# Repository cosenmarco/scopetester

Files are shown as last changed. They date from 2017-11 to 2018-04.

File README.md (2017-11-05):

# ScopeTester
An Open Hardware project for a small oscilloscope tester and calibrator with features like the [Hameg HZ-60](https://www.radiomuseum.org/r/hameg_scope_tester_hz_60.html).

## License
This project aims to be "open" in the sense of [Open Hardware](https://en.wikipedia.org/wiki/Open-source_hardware) and [Free Libre Open Source](https://en.wikipedia.org/wiki/Free_and_open-source_software).
The project is made available under the terms of the [Creative Commons license](https://creativecommons.org/licenses/by-sa/4.0/).

## Tools
The harware is developed using [KiCAD](http://kicad-pcb.org/).
Firmware is developed using [MPLAB X](http://www.microchip.com/mplab/mplab-x-ide) and the [XC8 compiler](http://www.microchip.com/mplab/compilers) from Microchip.



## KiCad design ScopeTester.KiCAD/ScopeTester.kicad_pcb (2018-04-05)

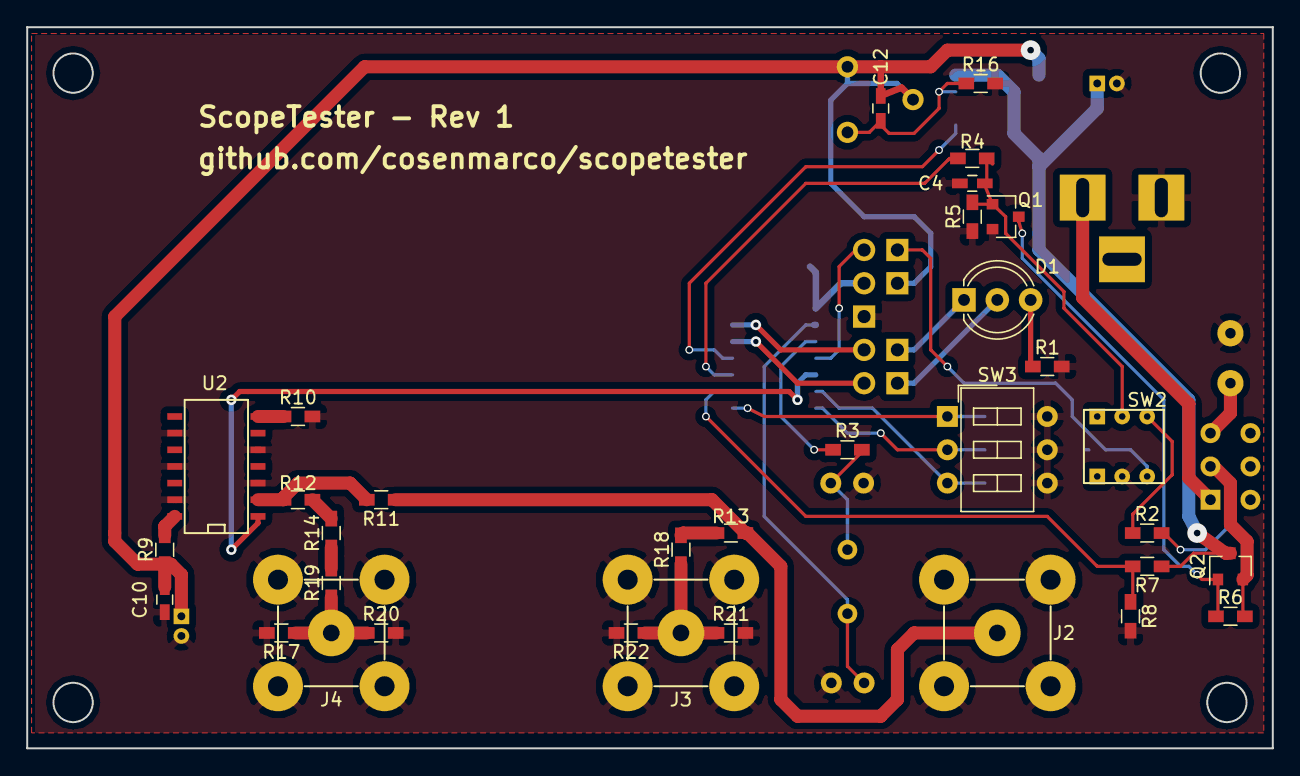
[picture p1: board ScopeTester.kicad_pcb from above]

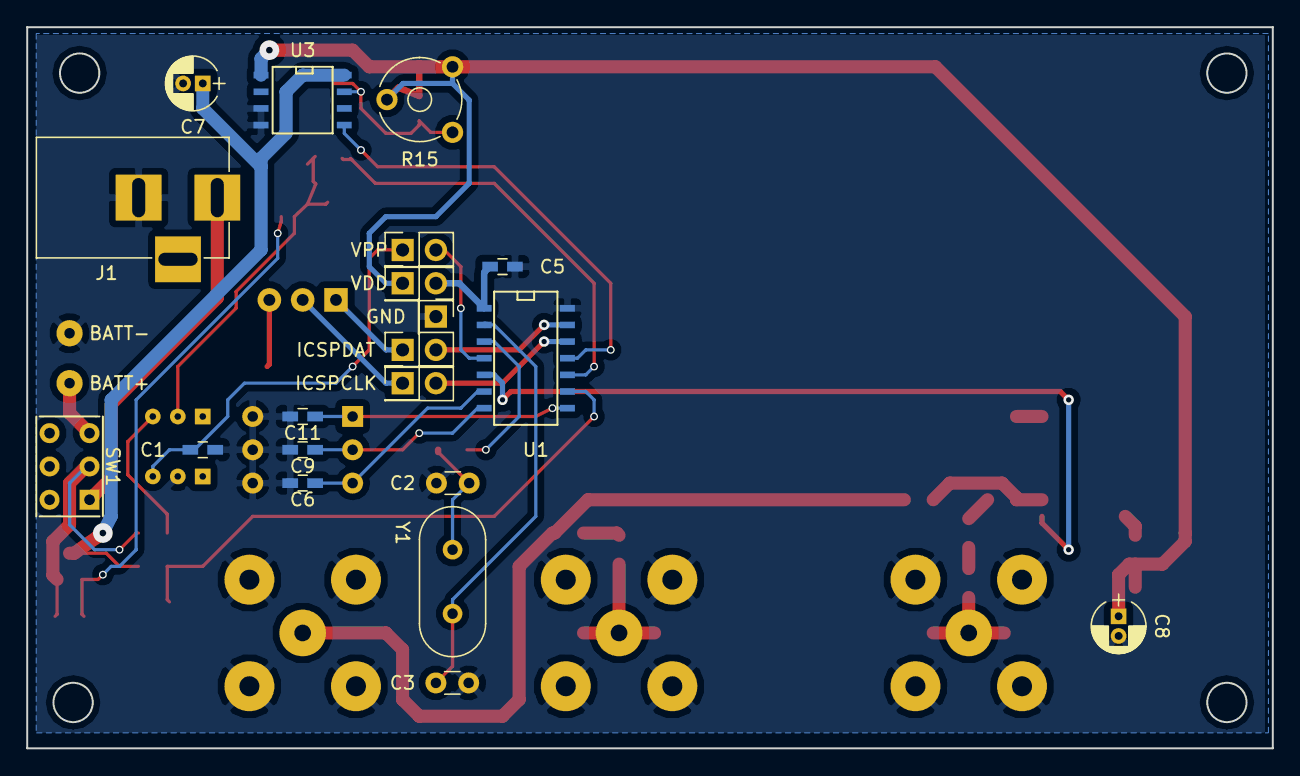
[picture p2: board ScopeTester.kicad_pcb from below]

Board: 2 copper layers, 95.0 x 55.0 mm, 55 parts (22 on the bottom side), 37 nets.

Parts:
BATT+: 4xLR6(AA); SolderWirePad_single_0-8mmDrill
BATT-: TEST; SolderWirePad_single_0-8mmDrill
C1: 330nF; C_0603_HandSoldering
C2, C3: 22pF; C_Disc_D3.0mm_W1.6mm_P2.50mm
C4: 0.22µF; C_0603_HandSoldering
C5: 100nF; C_0603_HandSoldering
C6, C9, C11: 0; C_0603_HandSoldering
C7: 3.3µF; CP_Radial_D4.0mm_P1.50mm
C8: 10µF; CP_Radial_D4.0mm_P1.50mm
C10, C12: 0.01µF; C_0603_HandSoldering
D1: ON/ERROR; LED_D5.0mm-3
GND: GND; Pin_Header_Straight_1x01_Pitch2.54mm
ICSPCLK: Jumper; Pin_Header_Straight_2x01_Pitch2.54mm
ICSPDAT: Jumper; Pin_Header_Straight_2x01_Pitch2.54mm
J1: 5VDC; BARREL_JACK
J2: 2.5Vpp; bnc-ci-large
J3: 250mV; bnc-ci-large
J4: 25mVpp into 50 Ohm; bnc-ci-large
Q1: BSS138; SOT-23
Q2: IRLML6401; SOT-23
R1: 560R; R_0603_HandSoldering
R2: 10K; R_0603_HandSoldering
R3: 0R; R_0603_HandSoldering
R4: 5K6; R_0603_HandSoldering
R5, R6: 56K; R_0603_HandSoldering
R7: 33k; R_0603_HandSoldering
R8: 12k; R_0603_HandSoldering
R9, R10: 15R; R_0603_HandSoldering
R11, R18: 150R; R_0603_HandSoldering
R12: 226R; R_0603_HandSoldering
R13: 301R; R_0603_HandSoldering
R14, R19: 1K5; R_0603_HandSoldering
R15: 220K; Potentiometer_Trimmer_Piher_PT-6v_Horizontal
R16: 100K; R_0603_HandSoldering
R17, R20, R21, R22: 100R; R_0603_HandSoldering
SW1: BATTERY/DC; SW_DPDT_Slide_mini
SW2: ON/OFF; DPDT_Button_mini
SW3: FREQ SEL; SW_DIP_x3_W7.62mm_Slide_LowProfile
U1: PIC16F1823-I/ST; SOIC-14_N
U2: 74AC14; SOIC-14_N
U3: TS2951; SOIC-8-N
VDD: Jumper; Pin_Header_Straight_2x01_Pitch2.54mm
VPP: Jumper; Pin_Header_Straight_2x01_Pitch2.54mm
Y1: 8.000Mhz; Crystal_HC49-4H_Vertical

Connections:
ERR: U1.11, U3.5
GND: BATT-.1, C1.2, C2.2, C3.2, C4.2, C5.1, C6.2, C7.2, C8.2, C9.2, C10.2, C11.2, GND.1, J1.2, J2.2, J3.2, J4.2, Q1.2, R1.2, R5.1, R8.2, R10.2, R16.2, R17.2, R20.2, R21.2, R22.2, SW2.5, SW3.4, SW3.5, SW3.6, U1.14, U2.3, U2.5, U2.9, U2.11, U2.13, U3.3, U3.4
unnamed: BATT+.1, SW1.3
unnamed: C2.1, R3.2, Y1.1
unnamed: C3.1, U1.2, Y1.2
unnamed: C4.1, Q1.1, R4.1, R5.2, SW2.2
unnamed: C5.2, U1.1, VDD.2
unnamed: C6.1, SW3.3, U1.6
unnamed: C7.1, Q2.3, R7.1, U3.8
unnamed: C9.1, SW3.2, U1.7
unnamed: C11.1, SW3.1, U1.8
unnamed: C12.2, R15.3, R16.1, U3.7
unnamed: D1.1, ICSPDAT.1
unnamed: D1.2, ICSPCLK.1
unnamed: D1.3, R1.1
unnamed: J1.1, SW1.1
unnamed: J2.1, R11.1, R13.2
unnamed: J3.1, R18.1, R21.1, R22.1
unnamed: J4.1, R17.1, R19.1, R20.1
unnamed: ICSPDAT.2, U1.13
unnamed: ICSPCLK.2, U1.12
unnamed: U1.4, VPP.2
unnamed: Q1.3, Q2.1, R6.1
unnamed: Q2.2, R2.2, R6.2, SW1.2
unnamed: R2.1, SW2.3
unnamed: R3.1, U1.3
unnamed: R9.2, U2.14
unnamed: R10.1, U2.7
unnamed: R11.2, R12.2, U2.2
unnamed: R12.1, R14.2
unnamed: R13.1, R18.2
unnamed: R14.1, R19.2
unnamed: U1.5, U2.1
SENSE: R7.2, R8.1, U1.9
SHUTDOWN: R4.2, U1.10
SWITCH: C1.1, SW2.6, VPP.1
VDD: C8.1, C10.1, C12.1, R9.1, R15.1, R15.2, U3.1, VDD.1

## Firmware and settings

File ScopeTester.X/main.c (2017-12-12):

/**
 * Scope Tester
 * Author: https://github.com/cosenmarco
 * License: https://creativecommons.org/licenses/by-sa/4.0/legalcode
 * Processor: PIC16F1823
 * This is the C (Microchip XC8 compiler) source for the project discussed at 
 * http://www.eevblog.com/forum/projects/oscilloscope-tester-like-hameg-hz60/
*/
#include <xc.h>
#include <stdint.h>

// CONFIG1
#pragma config FOSC = HS        // Oscillator Selection (HS Oscillator, High-speed crystal/resonator connected between OSC1 and OSC2 pins)
#pragma config WDTE = OFF       // Watchdog Timer Enable (WDT disabled)
#pragma config PWRTE = ON       // Power-up Timer Enable (PWRT enabled)
#pragma config MCLRE = OFF      // MCLR Pin Function Select (MCLR/VPP pin function is digital input)
#pragma config CP = OFF         // Flash Program Memory Code Protection (Program memory code protection is disabled)
#pragma config CPD = OFF        // Data Memory Code Protection (Data memory code protection is disabled)
#pragma config BOREN = ON       // Brown-out Reset Enable (Brown-out Reset enabled)
#pragma config CLKOUTEN = OFF   // Clock Out Enable (CLKOUT function is disabled. I/O or oscillator function on the CLKOUT pin)
#pragma config IESO = OFF       // Internal/External Switchover (Internal/External Switchover mode is disabled)
#pragma config FCMEN = OFF      // Fail-Safe Clock Monitor Enable (Fail-Safe Clock Monitor is disabled)

// CONFIG2
#pragma config WRT = OFF        // Flash Memory Self-Write Protection (Write protection off)
#pragma config PLLEN = ON       // PLL Enable (4x PLL enabled) -- Fosc will be 32MHz with our 8MHz crystal
#pragma config STVREN = ON      // Stack Overflow/Underflow Reset Enable (Stack Overflow or Underflow will cause a Reset)
#pragma config BORV = LO        // Brown-out Reset Voltage Selection (Brown-out Reset Voltage (Vbor), low trip point selected.)
#pragma config LVP = OFF        // Low-Voltage Programming Enable (Low-voltage programming disabled)

// OUTPUTS
#define LED_GRN LATAbits.LATA0
#define LED_RED LATAbits.LATA1
#define SHUTDOWN LATCbits.LATC0
#define OUT LATCbits.LATC5

// INPUTS
#define ERR PORTAbits.RA2
#define SWITCH PORTAbits.RA3
#define SENSE PORTCbits.C12IN1N
#define FSEL0 PORTCbits.RC2
#define FSEL1 PORTCbits.RC3
#define FSEL2 PORTCbits.RC4

#define SW_PRESSED 0
#define SW_RELEASED 1

#define SHTDN_KEEP_ON 1
#define SHTDN_TURN_OFF 0

#define DC_OUT_LEVEL 0

typedef enum { 
    F_1MHz,
    F_100KHz,
    F_10KHz,
    F_1KHz,
    F_100Hz,
    F_10Hz,
    F_1Hz,
    F_DC
} mode_t;

typedef struct {
    unsigned char prescale;
    unsigned char pr2Value;
    unsigned char ccpr1lValue;
    unsigned char dc1bValue;
} pwm_setup_t;

typedef struct {
    unsigned char prescale;
    unsigned char ccpr1hValue;
    unsigned char ccpr1lValue;
} compare_setup_t;

void turnOnGreenLed(void);
void turnOnRedLed(void);
unsigned readMode(void);
void setupMode(mode_t mode);
void setupPWM(pwm_setup_t setup);
void setupCompare(compare_setup_t setup);
void setupDC(void);
void checkPower(void);

void main(void) {
    
    INTCONbits.GIE = 1; // Enable global interrupt
    INTCONbits.PEIE = 1; // Enable peripheral interrupt
    
    // PORT A configuration
    PORTA = 0;
    ANSELA = 0;
    TRISA = 0b111100; // Input from the TS2951 Error pin and the ON/OFF button
    WPUA = 0b001100; // Weak Pull-up enalbed on ERR and SWITCH inputs
    
    // PORT C configuration
    PORTC = 0;
    ANSELC = 0;
    TRISC = 0b011110; // We use here RC0 for SHUTDOWN and RC5 as the signal OUT
    WPUC = 0b011100; // We want to pull-up all the frequency seletion switches

    OPTION_REGbits.nWPUEN = 0; // Enable Weak Pull-up resistors
   
    SHUTDOWN = SHTDN_KEEP_ON; // Make sure circuit stays ON
    
    // Setup FVR and Comparator for battery voltage sensing
    FVRCON = 0b10000100; // Fixed Voltage Reference is enabled (1x)
    CM1CON0 = 0b10000010; // Enable Comparator (direct, low speed, hysteresis)
    CM1CON1 = 0b00100001; // No INT, + on FVR, - on C12IN1-

    // Setup Timer0 to blink the red led if necessary
    OPTION_REGbits.TMR0CS = 0; // Fosc/4 (8MHz)
    OPTION_REGbits.PSA = 0; // Prescaler ON
    OPTION_REGbits.PS = 0b111; // Prescale at 256
    
    turnOnGreenLed();

    mode_t mode = F_DC;
    mode_t oldmode = F_DC;
    
    setupMode(F_DC);

    // Given how the circuit boots, it is expected that upon startup the
    // SWITCH is pressed. Do nothing until the user releases it.
    while(SWITCH == SW_PRESSED) continue;

    do {        
        checkPower();
        mode = readMode();
        if(mode != oldmode) {
            oldmode = mode;
            setupMode(mode);
        }
    } while(SWITCH == SW_RELEASED);
    
    // Do nothing while the user keeps the switch pressed
    while(SWITCH == SW_PRESSED) continue;
    
    // User released ON/OFF. Shutdown now.
    setupMode(F_DC);
    SHUTDOWN = SHTDN_TURN_OFF; // Turn off power supply
    while(1); // Wait forever.
}

void turnOnGreenLed(void) {
    LED_GRN = 1;
    LED_RED = 0;
}

void turnOnRedLed(void) {
    LED_GRN = 0;
    LED_RED = 1;
}

void toggleRedLed(void) {
    LED_GRN = 0;
    LED_RED = ~LED_RED;
}

unsigned readMode() {
    return (unsigned) ((FSEL2 << 2) + (FSEL1 << 1) + FSEL0);
}

// Values obtained for a Fosc = 32MHz
const pwm_setup_t pwm_setup[] = {
    // Prescale,   PR2,      CCPR1L,  CCP1CON
    {      0b00,     7,       0b100,     0b00  }, // F_1MHz
    {      0b00,    79,    0b101000,     0b00  }, // F_100KHz
    {      0b01,   199,   0b1100100,     0b00  }, // F_10KHz
    {      0b11,   124,    0b111110,     0b10  }  // F_1KHz
};

// Values obtained for a Fosc = 32MHz
const compare_setup_t compare_setup[] = {
// Prescale,  CCPR1H,  CCPR1L
    {  0b00,    0x0F,    0xA0 }, // F_100Hz: Every 4000 (0xFA0) counts
    {  0b00,    0x9C,    0X40 }, // F_10Hz: Every 40000 (0x9C40) counts
    {  0b11,    0XC3,    0x50 }  // F_1Hz: Every 50000 (0xC350) counts
};

/**
 * Sets up the operating frequency which will be generated at pin OUT.
 * The modes F_1MHz to F_1KHz use the PWM module according to the config
 * table stored in pwm_setup.
 * The modes F_100Hz to F_1Hz use the Compare mode to generate an interrupt
 * at different frequencies. The ISR will always divide this frequency by
 * 10, so this must be taken into account in the setup of Timer1 and CCPR1.
 * Clocking Timer1 from the system clock (F OSC ) should not be used in Compare
 * mode. This means Fosc/4 is 8MHz
 * @param mode The chosen operating mode
 */
void setupMode(mode_t mode) {
    setupDC(); // Reset everything and provide default

    switch(mode) {
        case F_1MHz:
        case F_100KHz:
        case F_10KHz:
        case F_1KHz:
            setupPWM(pwm_setup[mode]);
            break;

        case F_100Hz:
        case F_10Hz:
        case F_1Hz:
            setupCompare(compare_setup[mode - F_100Hz]);
            break;
    }
}

void setupPWM(pwm_setup_t setup) {
    // Configure Timer2 and PWM
    T2CONbits.T2CKPS = setup.prescale;
    PR2 = setup.pr2Value;
    CCPR1L = setup.ccpr1lValue;
    CCP1CONbits.DC1B = setup.dc1bValue;
    TMR2 = 0xFF;

    // Start Timer2 and PWM
    CCP1CONbits.CCP1M = 0b1100; // PWM mode: P1A, P1C active-high; P1B, P1D active-high
    T2CONbits.TMR2ON = 1;
}

void setupCompare(compare_setup_t setup) {
    PIE1bits.CCP1IE = 1; // Enables the CCP1 interrupt
    CCP1CONbits.CCP1M = 0b1010; // Compare mode: generate software interrupt only
    T1CONbits.TMR1CS = 0b00; // Fosc/4 (8MHz)
    T1CONbits.T1CKPS = setup.prescale;
    CCPR1H = setup.ccpr1hValue;
    CCPR1L = setup.ccpr1lValue;
    T1CONbits.TMR1ON = 1; // Turn ON Timer1
}

void setupDC() {
    CCP1CONbits.CCP1M = 0; // Capture/Compare/PWM off (resets ECCP1 module)
    OUT = DC_OUT_LEVEL; // Set OUT to the correct logic level to have a pure DC output

    // Turn OFF and reset Timer1
    T1CONbits.TMR1ON = 0;
    TMR1L = 0;
    TMR1H = 0;

    T2CONbits.TMR2ON = 0; // Turn off Timer2
    PIE1bits.CCP1IE = 0; // Disables the CCP1 interrupt
}

unsigned char blinkState = 0;
void checkPower() {
    if (!ERR) { // ERR is active LOW
        if (INTCONbits.T0IF) {
            INTCONbits.T0IF = 0; // Clear interrupt bit
            if (++blinkState > 50) {
                blinkState = 0;
                toggleRedLed();
            }
        }
    } else {
        blinkState = 0;
        if (FVRCONbits.FVRRDY && CM1CON0bits.C1OUT) { 
            turnOnRedLed();
        } else {
            turnOnGreenLed();
        }
    }
}
               
volatile unsigned char ocState = 0;
void interrupt isr(void) {
    if (PIR1bits.CCP1IF) {
        PIR1bits.CCP1IF = 0; // Clear interrupt bit
        
        // Resets the Timer1
        TMR1H = 0;
        TMR1L = 0;

        // Every 10 calls toogle the OUT pin
        if (++ocState >= 10) {
            ocState = 0;
            OUT = ~OUT;
        }
    }    
}

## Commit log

2017-11-05 Project in Github
    [ScopeTester.sch]
2017-11-10 Using PWM mode or higher frequencies
2017-11-11 Adding led management code and editorconfig
2017-12-12 Fixing a few small issues
    [main.c]
2018-03-11 Adding PCB Rev 1
    [ScopeTester.kicad_pcb, ScopeTester.sch]
2018-04-05 Hopefully fixing missing libraries issue at .sch loading
    [ScopeTester.kicad_pcb]
2026-08-12 Attempt to fix kicad project for newer versions
    [ScopeTester-2026-08-12-21-49-14.sch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]

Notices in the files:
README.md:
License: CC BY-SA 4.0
